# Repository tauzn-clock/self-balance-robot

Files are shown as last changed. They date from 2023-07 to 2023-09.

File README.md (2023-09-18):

## Self Balance Robot

This repo serves as a record of my attempt to build a self-balancing robot (affectionately called rat :D ).

https://github.com/tauzn-clock/self-balancing-robot/assets/72295649/7475527e-0695-4e05-951b-1d8318b3db41

### Bill of Materials:
- [Node MCU](https://www.ebay.co.uk/itm/263729724888)
- [MPU6050 IMU](https://www.amazon.co.uk/dp/B0957SJL6D?psc=1&ref=ppx_yo2ov_dt_b_product_details)
- [L298N H-Bridge Controller + Motors](https://www.amazon.co.uk/dp/B07ZT5CCFV?psc=1&ref=ppx_yo2ov_dt_b_product_details)
- 9V Battery
- Ribbon Cables
- Custom PCB Board (See `PCB_files`)

### Installation
> [!WARNING]  
> Turn off 9V power when connected to Node MCU
1) Download Visual Studio Code
2) Install the [Platform IO Extension](https://platformio.org/)
3) Build `/src/main.cpp` and flash to Node MCU

### Tips on Tuning
- Tuning Parameters found under `/include/control/balance.cpp` are specific to my robot. These may defer if different components are used.
- Typically, the IMU comes with a slight offset specific to each component.

### Future Improvements:
- Mounting holes in PCB board are too small for M3 threads, and require some filing
- Shift wheel motor mounting points closer to the edge
- After prolonged usage, wheels do not rotate at magnitudes lower than 0.5 (Due to friction within the motor?)
- Include directional control based on Node MCU's Wifi Module?

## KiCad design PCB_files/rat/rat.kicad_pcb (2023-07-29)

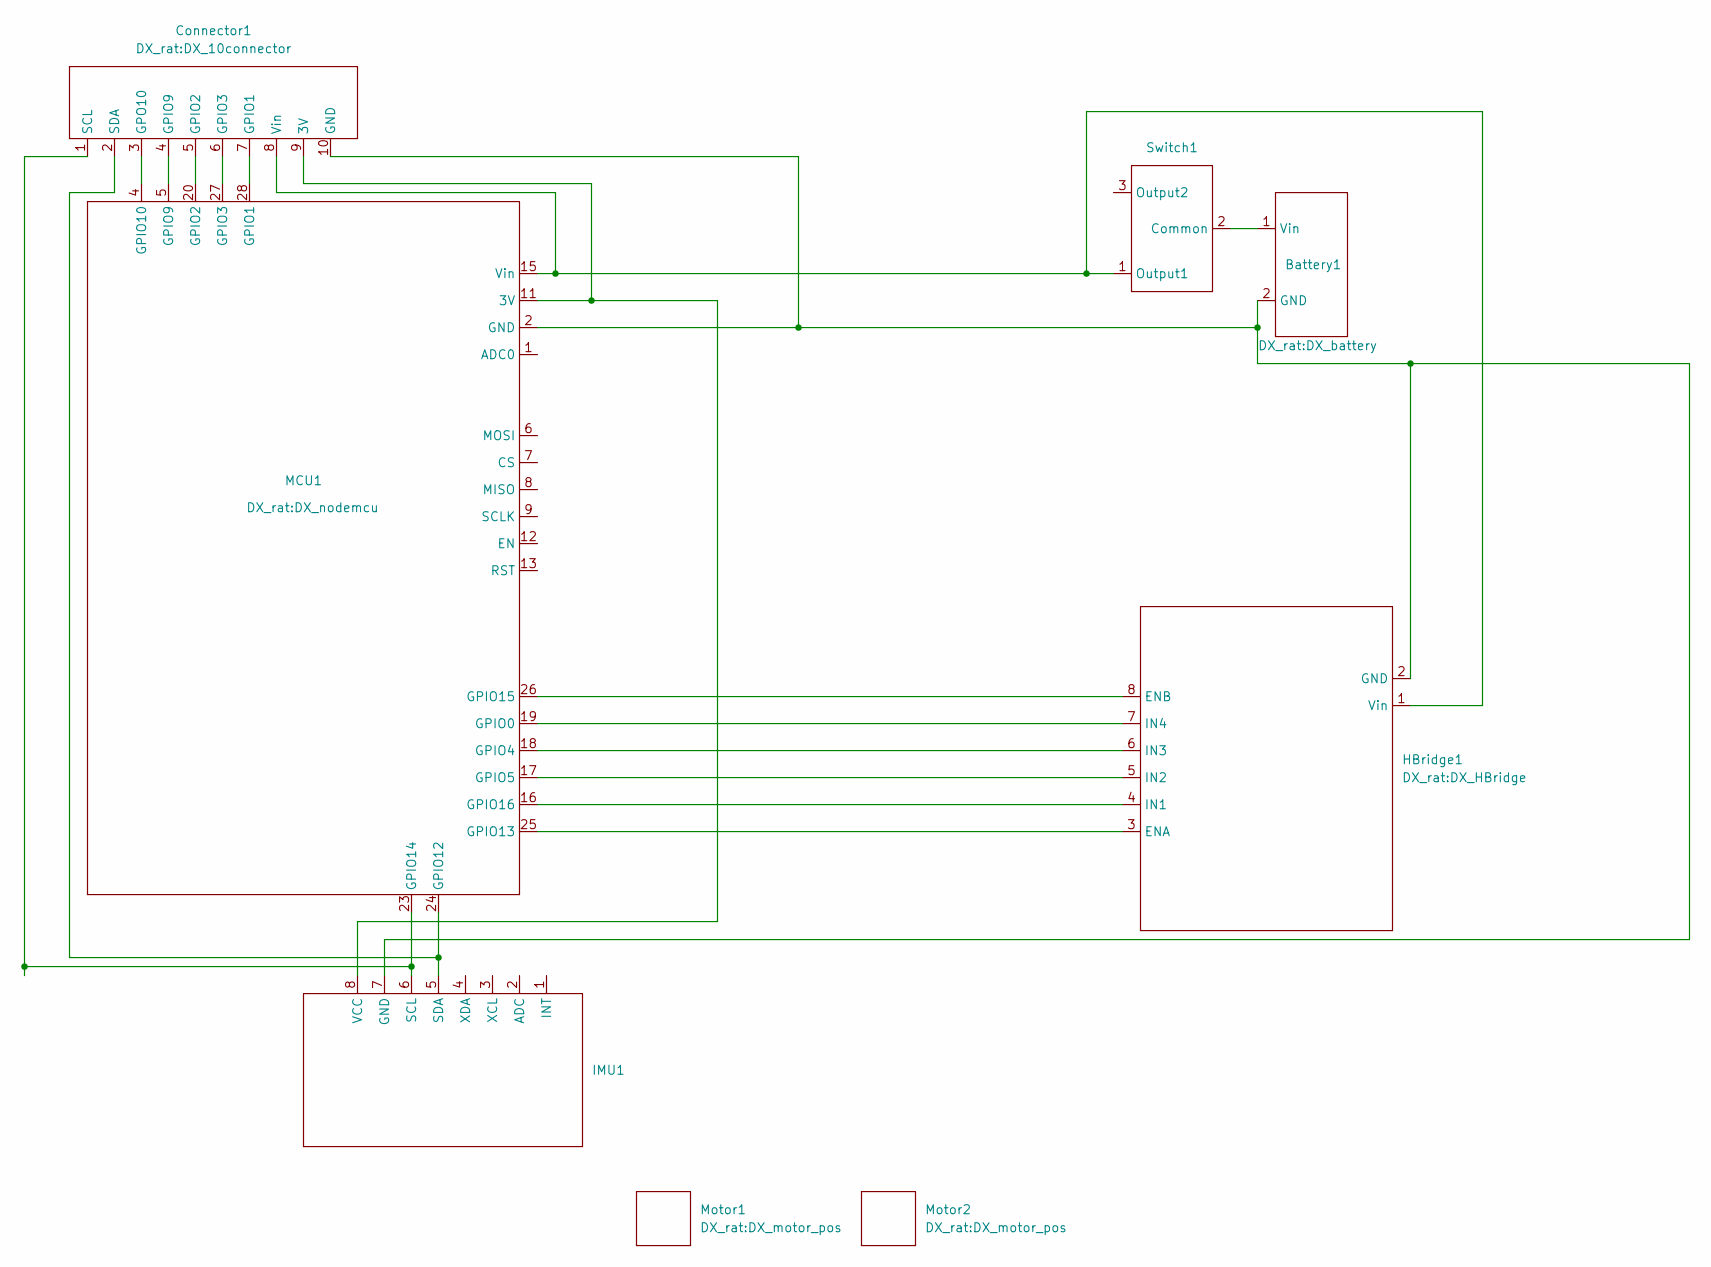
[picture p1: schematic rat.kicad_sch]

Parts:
Battery1: DX_battery
Connector1: DX_10connector
HBridge1: DX_HBridge
IMU1: DX_imu
MCU1: DX_nodemcu
Motor1, Motor2: DX_motor_pos
Switch1: DX_Switch

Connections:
unnamed: Battery1.2 (GND), Connector1.10 (GND), HBridge1.2 (GND), IMU1.7 (GND), MCU1.2 (GND), MCU1.10 (GND), MCU1.14 (GND), MCU1.22 (GND), MCU1.29 (GND)
unnamed: Battery1.1 (Vin), Switch1.2 (Common)
unnamed: Connector1.9 (3V), IMU1.8 (VCC), MCU1.11 (3V), MCU1.21 (3V), MCU1.30 (3V)
unnamed: Connector1.7 (GPIO1), MCU1.28 (GPIO1)
unnamed: Connector1.5 (GPIO2), MCU1.20 (GPIO2)
unnamed: Connector1.6 (GPIO3), MCU1.27 (GPIO3)
unnamed: Connector1.4 (GPIO9), MCU1.5 (GPIO9)
unnamed: Connector1.3 (GPO10), MCU1.4 (GPIO10)
unnamed: Connector1.1 (SCL), IMU1.6 (SCL), MCU1.23 (GPIO14)
unnamed: Connector1.2 (SDA), IMU1.5 (SDA), MCU1.24 (GPIO12)
unnamed: Connector1.8 (Vin), HBridge1.1 (Vin), MCU1.15 (Vin), Switch1.1 (Output1)
unnamed: HBridge1.3 (ENA), MCU1.25 (GPIO13)
unnamed: HBridge1.8 (ENB), MCU1.26 (GPIO15)
unnamed: HBridge1.4 (IN1), MCU1.16 (GPIO16)
unnamed: HBridge1.5 (IN2), MCU1.17 (GPIO5)
unnamed: HBridge1.6 (IN3), MCU1.18 (GPIO4)
unnamed: HBridge1.7 (IN4), MCU1.19 (GPIO0)

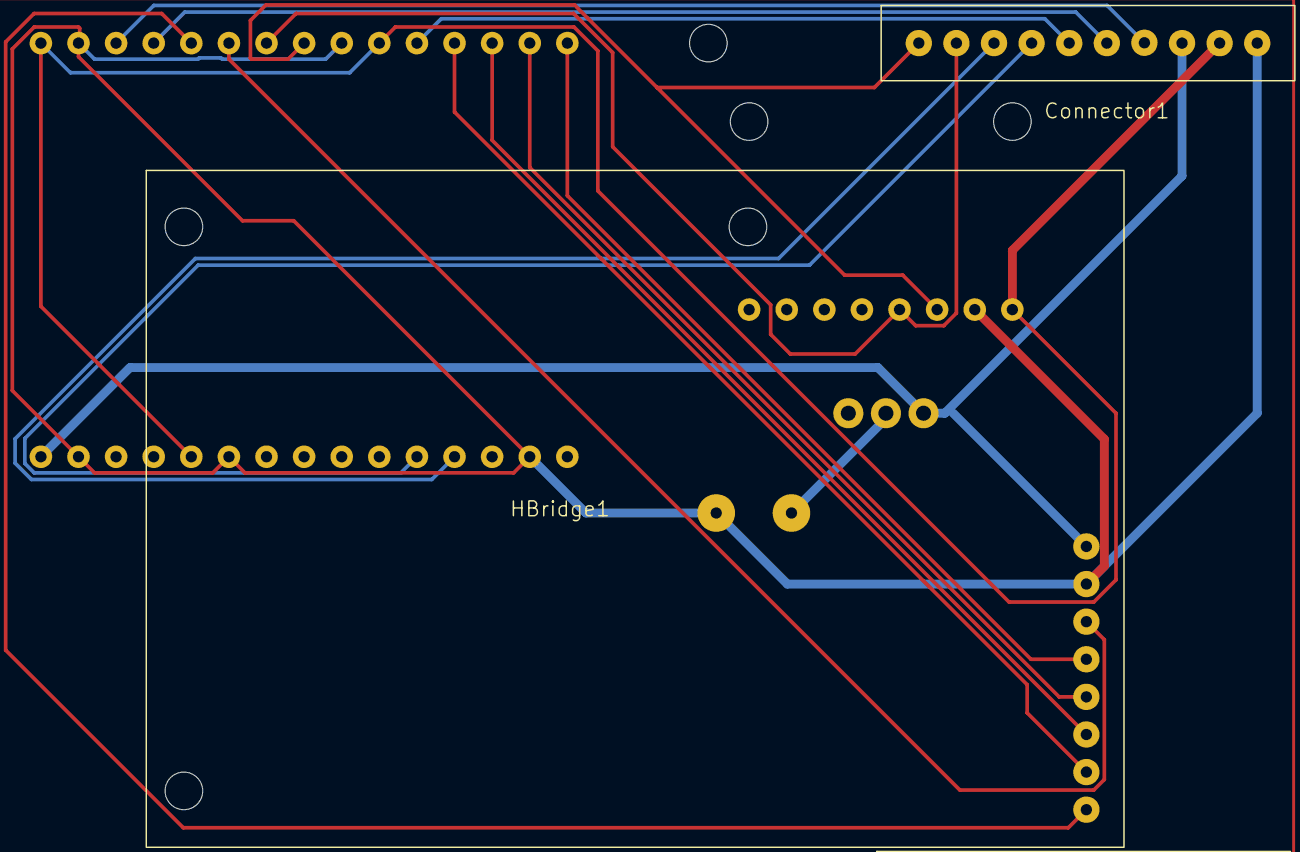
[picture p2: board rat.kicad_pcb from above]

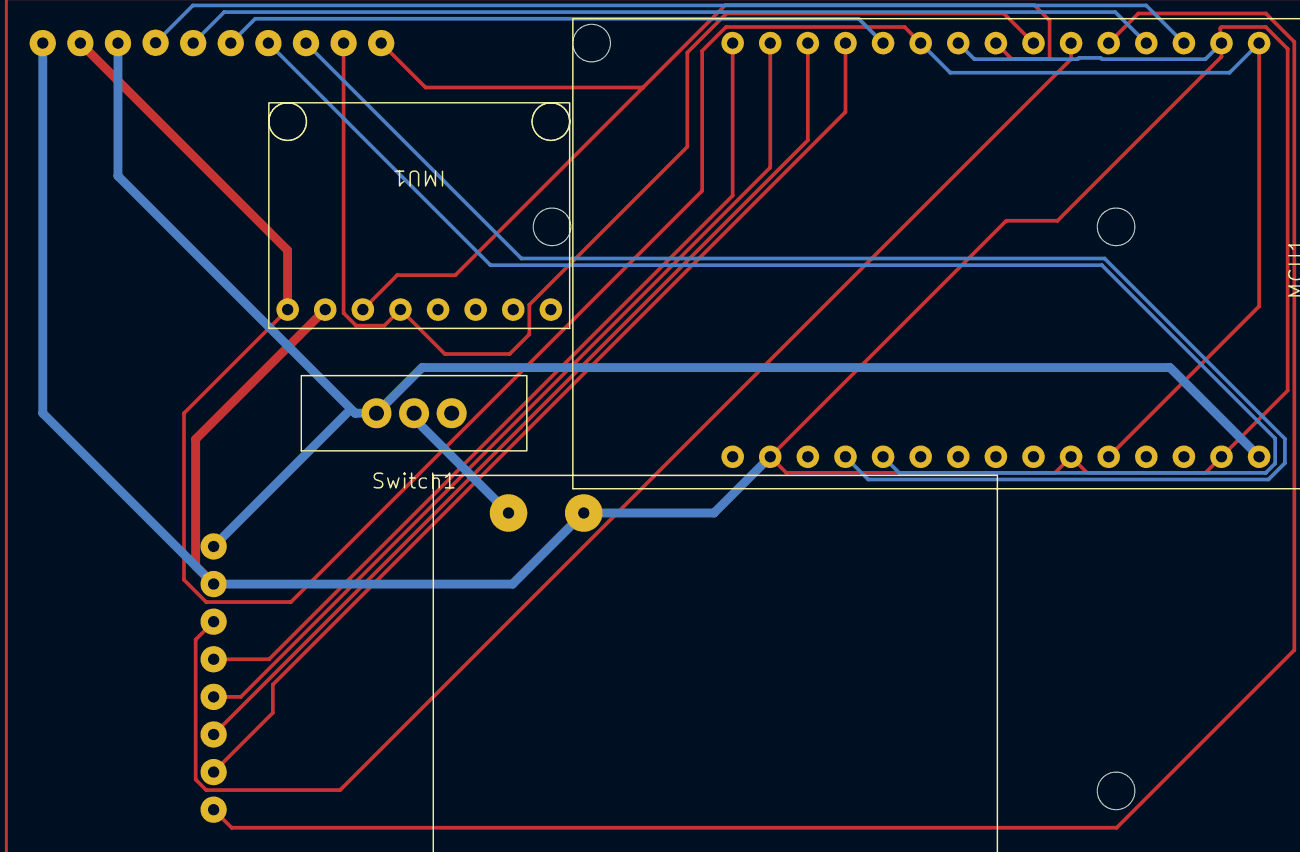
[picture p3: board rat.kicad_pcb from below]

Board: 2 copper layers, 8 parts (4 on the bottom side), 17 nets.

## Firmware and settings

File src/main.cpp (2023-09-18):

#include <Arduino.h>
#include <Wire.h>
#include <SPI.h>
//#include "../include/screen/screen.cpp"
#include "../include/imu/imu.cpp"
#include "../include/wheel/wheel.cpp"
#include "../include/control/balance.cpp"
#include "../include/control/manual.cpp"
#include "../include/wifi/wifiDirection.cpp"

#define DEBUG false

IMU imu;
WHEEL wheel1(D7,D0,D1);
WHEEL wheel2(D8,D2,D3);
BALANCE balance;
MANUAL manual;

void setup() 
{    
   Serial.begin(115200);
   Wire.begin(D6,D5);
   imu.initIMU();
   wheel1.initWheel();
   wheel2.initWheel();

   //setupWifi(); TODO: Wifi Control
}

void loop()
{ 
   imu.getEvents(); 
   float balanceMag = balance.balanceController(imu.a.acceleration,imu.g.gyro);
   wheel1.setSpeed(balanceMag);
   wheel2.setSpeed(balanceMag);
   /*
   TODO: Wifi Control
   int direction = loopWifi();
   manual.handleInput(direction);
   wheel1.setSpeed(balanceMag + manual.leftWheel);
   wheel2.setSpeed(balanceMag + manual.rightWheel);
   */

   if (DEBUG){
      Serial.printf("Accel.x: %f\n",imu.a.acceleration.x);
      Serial.printf("Accel.y: %f\n",imu.a.acceleration.y);
      Serial.printf("Accel.z: %f\n",imu.a.acceleration.z);
      float accel_mag = imu.a.acceleration.x*imu.a.acceleration.x + imu.a.acceleration.y*imu.a.acceleration.y + imu.a.acceleration.z*imu.a.acceleration.z;
      accel_mag = pow(accel_mag,0.5);
      Serial.printf("Accel Mag:%f\n",accel_mag);
      Serial.printf("Gyro.y: %f\n",imu.g.gyro.y);
      Serial.printf("Angle: %f\n",balance.getTheta(imu.a.acceleration));
      Serial.println("Still Alive");
   }
}

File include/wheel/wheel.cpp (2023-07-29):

#ifndef WHEEL_INTERFACE
#define WHEEL_INTERFACE

#include <Arduino.h>
#include <Wire.h>
#include <SPI.h>

class WHEEL{
public:
    int MAG, FOR, BAC;
    WHEEL(int _mag, int _for, int _bac): MAG(_mag), FOR(_for), BAC(_bac){}

    void initWheel(){
        pinMode(MAG, OUTPUT);
        pinMode(FOR, OUTPUT);
        pinMode(BAC, OUTPUT);
    }

    void setSpeed(float s){
        //Set threshold
        if (s>1) s=1;
        if (s<-1) s=-1;

        if (s>0){
            digitalWrite(FOR, LOW);
            digitalWrite(BAC, HIGH);
            analogWrite(MAG, (255*s));
        }
        else{
            digitalWrite(FOR, HIGH);
            digitalWrite(BAC, LOW);
            analogWrite(MAG, -(255*s));
        }
    }

    void stop(){
        digitalWrite(FOR, LOW);
        digitalWrite(BAC, LOW);
    }
};  

#endif
